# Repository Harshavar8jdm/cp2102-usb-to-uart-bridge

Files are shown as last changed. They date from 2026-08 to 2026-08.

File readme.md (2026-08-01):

# CP2102N USB-C to UART Bridge Module

## Description
A 32x16mm, two-layer USB-to-UART bridge converter based on the Silicon Labs CP2102N. This board provides a serial interface for hardware development and debugging.

The design includes specific additions to address reliability issues common in similar modules, specifically the addition of TVS diodes for ESD protection and proper CC pin termination for USB-C standard compliance.

## Specifications
*   **Controller:** Silicon Labs CP2102N
*   **Connector:** USB Type-C
*   **Logic Level:** 3.3V (with 5V VBUS passthrough)
*   **Dimensions:** 32mm x 16mm
*   **PCB Layers:** 2
*   **EDA Tool:** KiCad

## Hardware Features
*   **ESD Protection:** uClamp3601P TVS diodes on the VBUS, D+, and D- lines, placed at the connector to clamp transient voltages.
*   **USB-C Termination:** Independent 5.1k Ohm pull-down resistors (R1, R2) on the CC1 and CC2 pins for host detection with C-to-C cables.
*   **Layout:** Continuous bottom ground plane for return paths. Decoupling capacitors (C1-C4) are routed near the IC power pins.
*   **Pinout:** 3V3, GND, TXD, RXD, and 5V broken out to a standard 2.54mm pitch header.

## Board Images

### Schematic
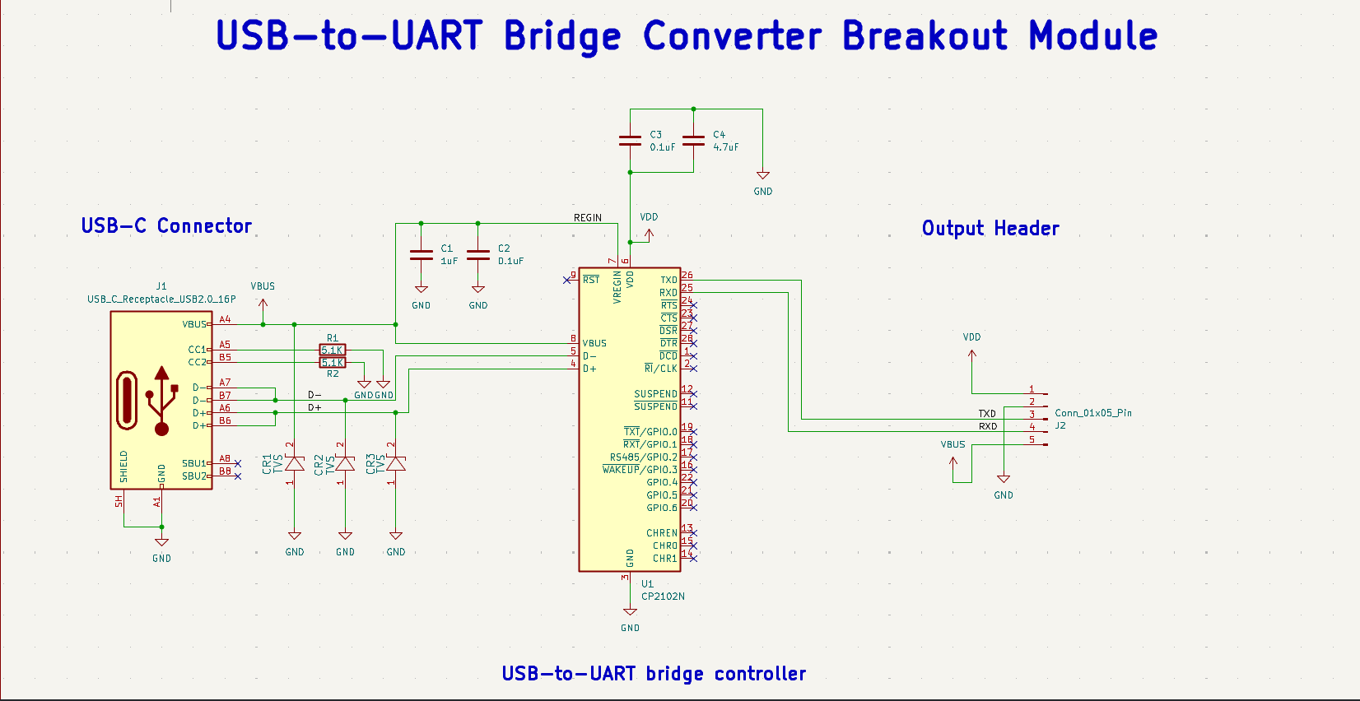
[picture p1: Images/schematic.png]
Schematic


### PCB Layout (Revised)
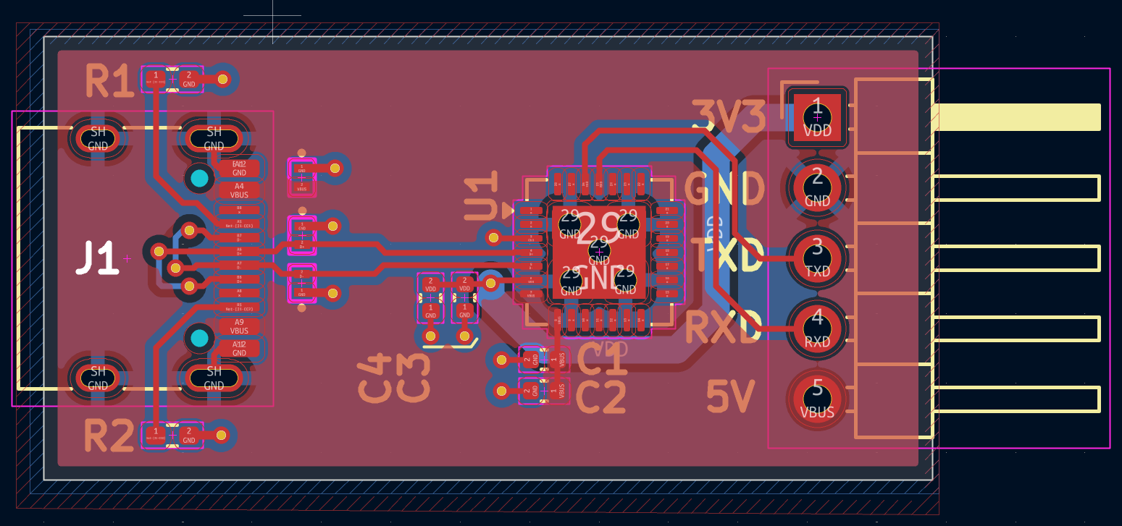
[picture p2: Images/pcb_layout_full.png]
PCB Layout

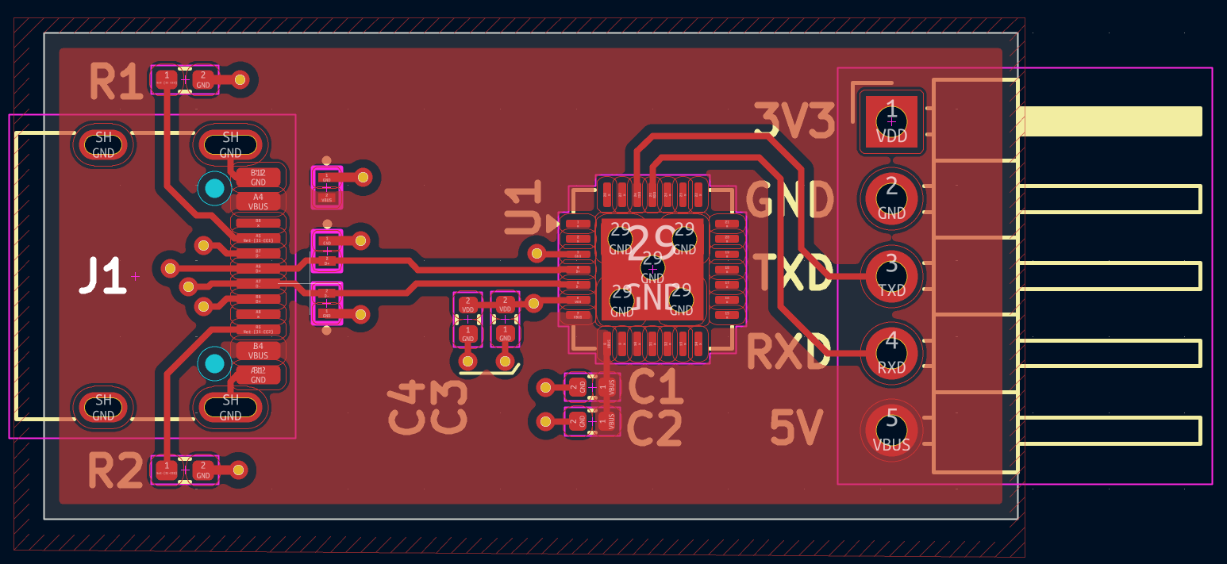
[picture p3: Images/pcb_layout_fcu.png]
PCB Layout

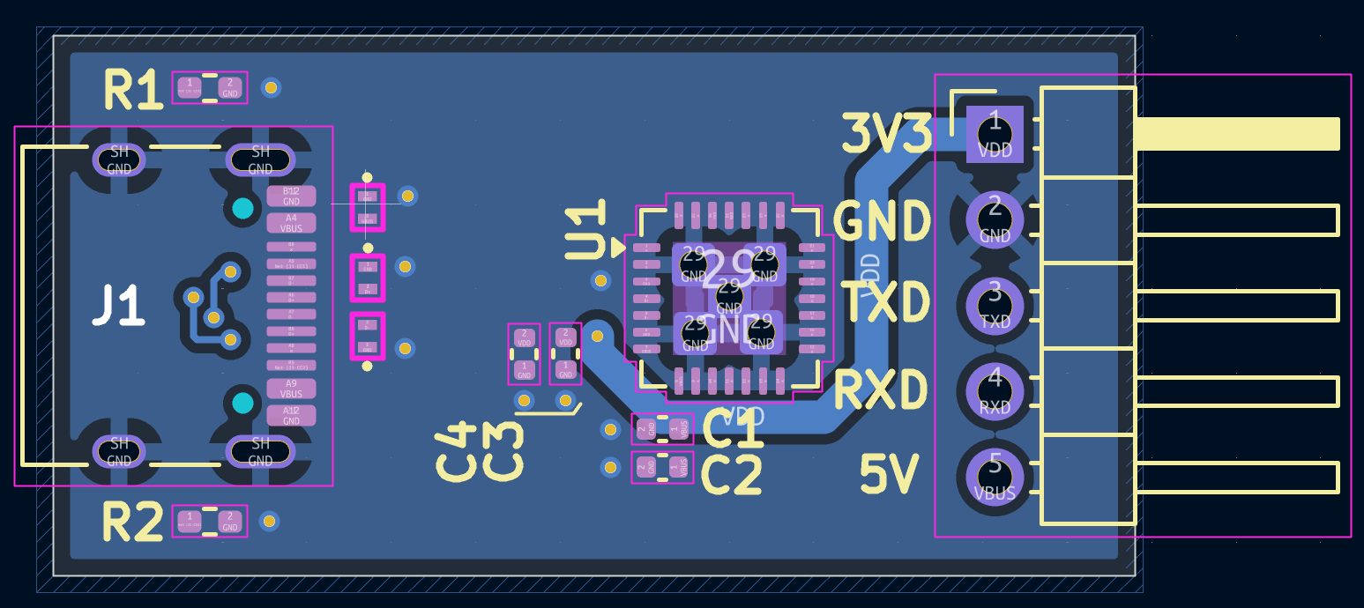
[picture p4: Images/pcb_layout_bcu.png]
PCB Layout


### 3D Render (Top)
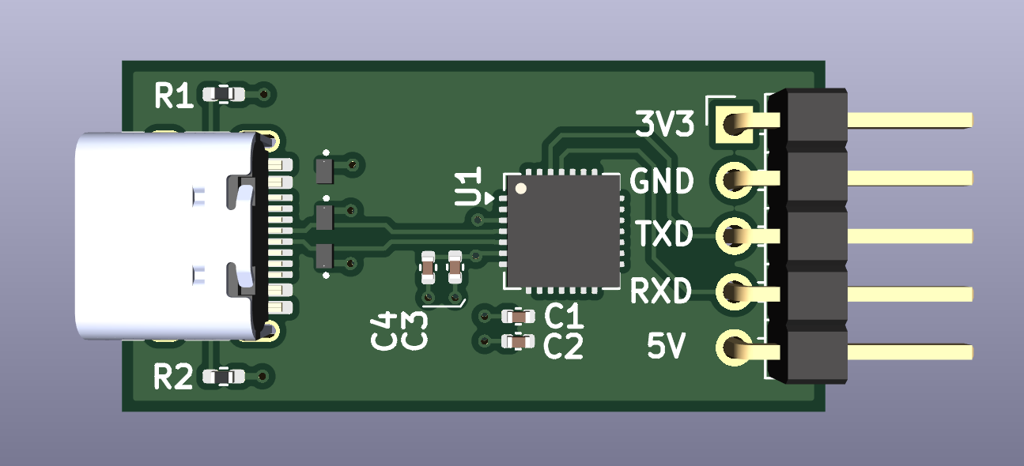
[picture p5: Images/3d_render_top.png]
3D Render Top


### 3D Render (Bottom)
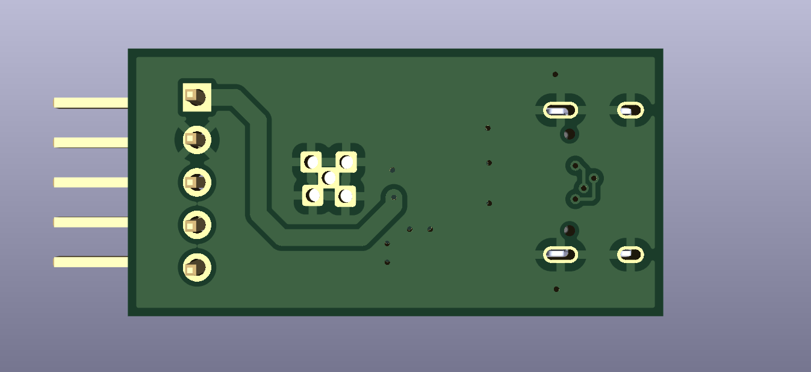
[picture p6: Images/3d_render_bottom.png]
3D Render Bottom


## Assembly Notes
The CP2102N utilizes a QFN-28 package with an exposed center pad. Solder paste and a reflow profile or hot plate are required for correct termination of the ground pad. The TVS diodes and passives are standard surface mount components.

## Author
Harsha

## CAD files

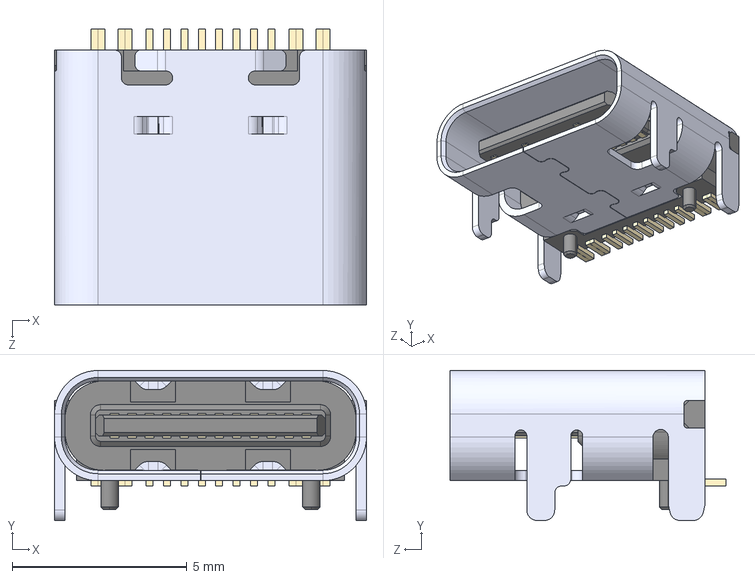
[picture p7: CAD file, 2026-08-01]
ext-libs/TYPE-C-31-M-12--3DModel-STEP-56544.STEP
8.94 x 4.30 x 7.90 mm

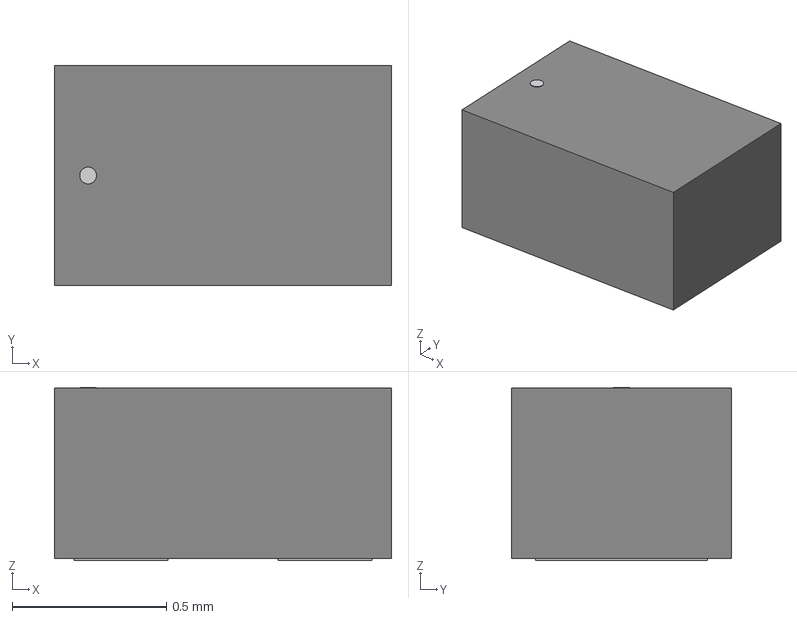
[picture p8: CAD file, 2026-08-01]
ext-libs/UCLAMP3601P_TNT/SLP1006P2_SEM.step
1.09 x 0.712 x 0.561 mm

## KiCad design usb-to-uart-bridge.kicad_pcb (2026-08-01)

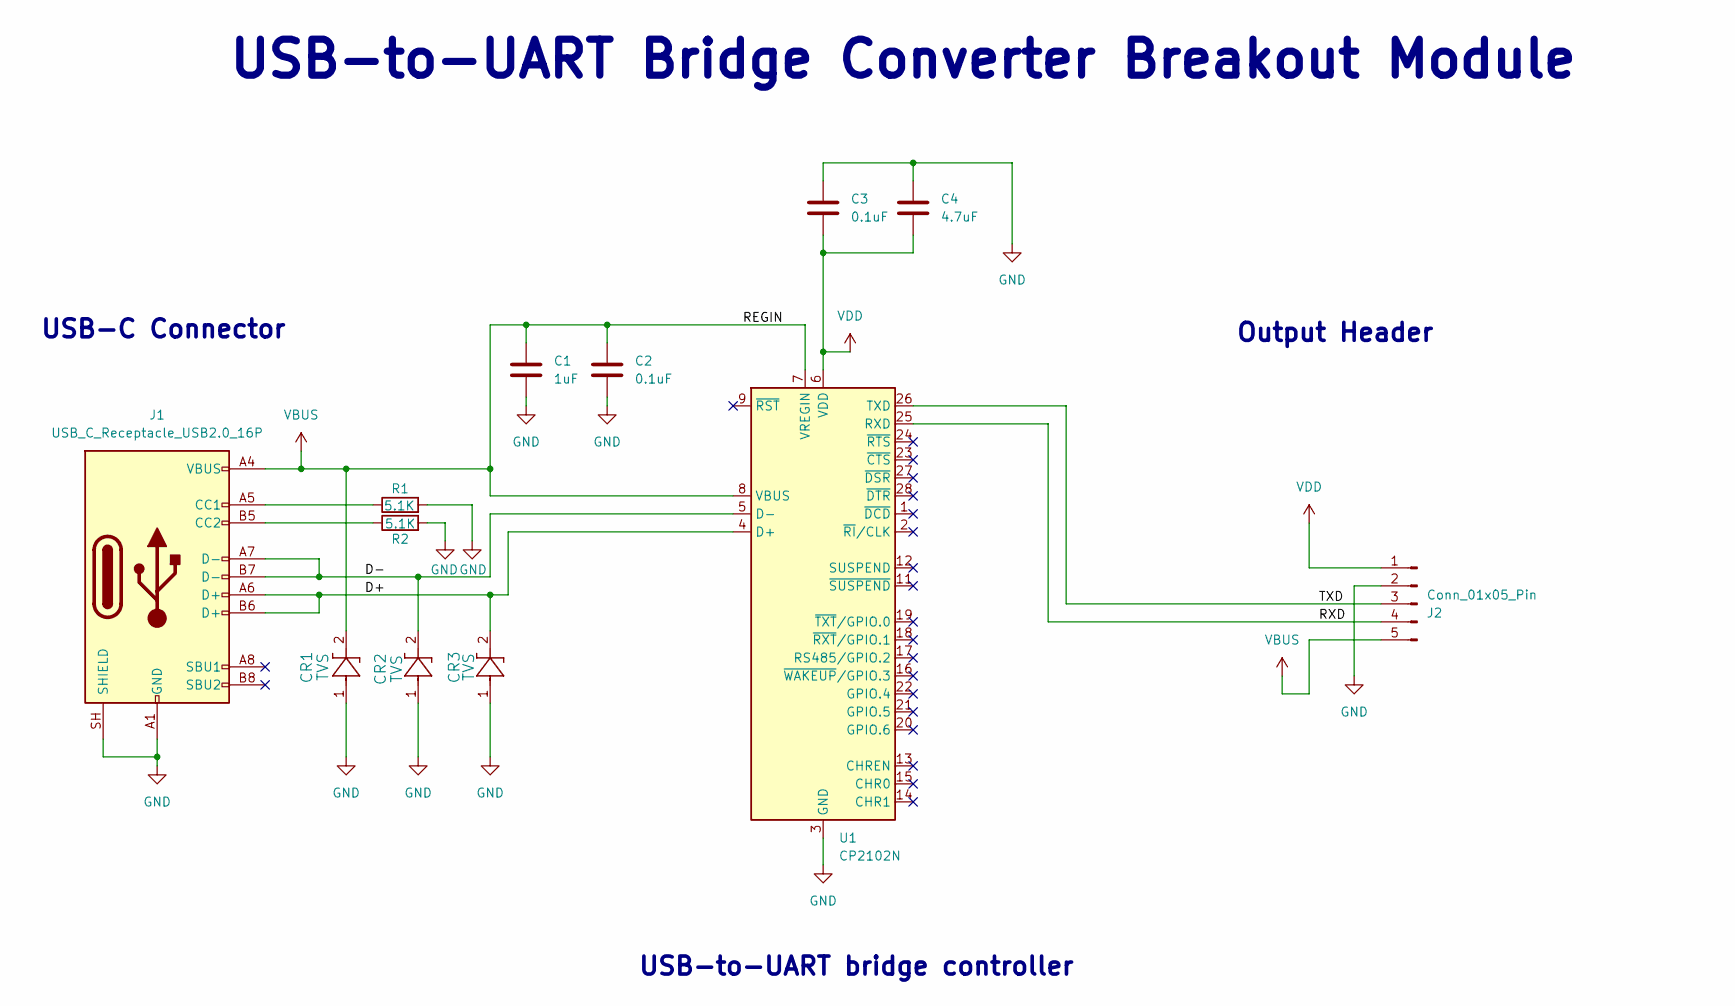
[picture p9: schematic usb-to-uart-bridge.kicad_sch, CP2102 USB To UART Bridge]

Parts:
C1: 1uF; C_0402_1005Metric
C2, C3: 0.1uF; C_0402_1005Metric
C4: 4.7uF; C_0402_1005Metric
CR1, CR2, CR3: TVS; SLP1006P2_SEM
J1: USB_C_Receptacle_USB2.0_16P; USB_C_Receptacle_HRO_TYPE-C-31-M-12
J2: Conn_01x05_Pin; PinHeader_1x05_P2.54mm_Horizontal
R1, R2: 5.1K; R_0402_1005Metric_Pad0.72x0.64mm_HandSolder
U1: CP2102N; QFN-28-1EP_5x5mm_P0.5mm_EP3.35x3.35mm

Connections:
/D+: CR3.2, J1.A6 (D+), J1.B6 (D+), U1.4 (D+)
/D-: CR2.2, J1.A7 (D-), J1.B7 (D-), U1.5 (D-)
/RXD: J2.4, U1.25 (RXD)
/TXD: J2.3, U1.26 (TXD)
GND: C1.2, C2.2, C3.1, C4.1, CR1.1, CR2.1, CR3.1, J1.A1 (GND), J1.A12 (GND), J1.B1 (GND), J1.B12 (GND), J1.SH (SHIELD), J2.2, R1.2, R2.2, U1.3 (GND), U1.29 (GND)
unnamed: J1.A5 (CC1), R1.1
unnamed: J1.B5 (CC2), R2.1
VBUS: C1.1, C2.1, CR1.2, J1.A4 (VBUS), J1.A9 (VBUS), J1.B4 (VBUS), J1.B9 (VBUS), J2.5, U1.7 (VREGIN), U1.8 (VBUS)
VDD: C3.2, C4.2, J2.1, U1.6 (VDD)

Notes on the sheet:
USB-C Connector
Output Header
USB-to-UART Bridge Converter Breakout Module
USB-to-UART bridge controller

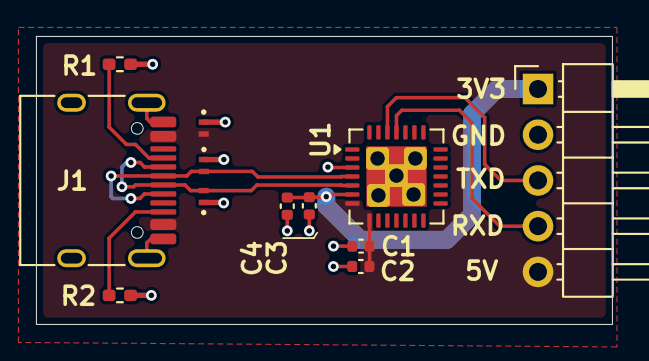
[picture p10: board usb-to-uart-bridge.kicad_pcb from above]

Board: 2 copper layers, 32.0 x 16.0 mm, 12 parts (0 on the bottom side), 9 nets.

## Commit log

2026-08-01 Completed Routing and Silkscreen
    [SLP1006P2_SEM.step, TYPE-C-31-M-12--3DModel-STEP-56544.STEP, usb-to-uart-bridge.kicad_pcb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]
2026-08-01 Updated Schematic and Layout with CC Resistors
    [usb-to-uart-bridge.kicad_pcb, usb-to-uart-bridge.kicad_sch]
2026-08-01 Gerber files were added
    [usb-to-uart-bridge-B_Cu.gbr, usb-to-uart-bridge-B_Mask.gbr, usb-to-uart-bridge-B_Paste.gbr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]
